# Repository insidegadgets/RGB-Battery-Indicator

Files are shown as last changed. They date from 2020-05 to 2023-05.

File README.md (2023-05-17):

# RGB-Battery-Indicator
Add an RGB battery indicator to any device you like to monitor the battery level.
Default firmware is for a LiPo.

License: CC-BY-NC

Order the board at 0.8mm thickness if installing in Gameboy. Likely some shell cutting will be required.
You'll need a programmer like a USBasp.
Check the picture for the parts placement.
Not recommended for beginners.

Order PCBs here or use the included gerbers:
https://oshpark.com/shared_projects/viN5ewHZ

ATTINY13A-MMFR

1M 0603

220K 0603

39K 0603

15K 0603

2x 5K 0603

2x 0.1uF 0603

1206 RGB LED - https://www.aliexpress.com/item/32382731373.html

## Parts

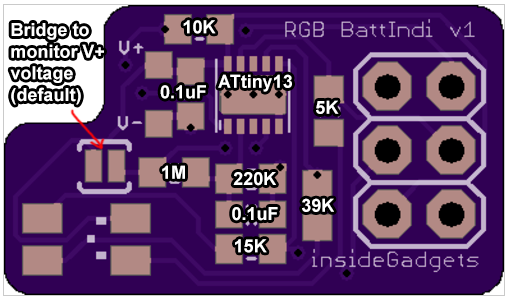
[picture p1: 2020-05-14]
Parts placement.png

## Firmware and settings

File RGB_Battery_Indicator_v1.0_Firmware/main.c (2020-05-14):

/*
 RGB Battery Indicator
 Version: 1.0
 Author: Alex from insideGadgets (www.insidegadgets.com)
 Created: 14/05/2020
 Last Modified: 14/05/2020
 
 Suitable for monitoring LiPo batteries
 
 */

#define F_CPU 1000000

#include <avr/io.h>
#include <avr/wdt.h>
#include <avr/interrupt.h>
#include <avr/sleep.h>
#include <util/delay.h>
#include "setup.c"

int main(void) {
	setup();
	
	uint8_t rgbColour = 0;
	
	while (1) {
		// 5 samples over 25ms
		uint16_t batteryVoltageLevel = 0;
		for (uint8_t x = 0; x < 5; x++) {
			batteryVoltageLevel += adc_read(batteryADCPin, ADC_REF_1_1V);
			_delay_ms(5);
		}
		batteryVoltageLevel = batteryVoltageLevel / 5;
		
		
		int greenHysterious = 0;
		int blueHysterious = 0;
		if (rgbColour == 2) { // Green
			greenHysterious = -10;
		}
		else if (rgbColour == 1) { // Blue
			greenHysterious = 10;
		}
		else { // Red
			blueHysterious = 10;
		}
		
		
		// Green
		if (batteryVoltageLevel >= (650 + greenHysterious)) { // 3.8v
			PORTB &= ~(1<<RGB_GREEN);
			PORTB |= (1<<RGB_RED);
			PORTB |= (1<<RGB_BLUE);
			rgbColour = 2;
		}
		
		// Blue
		else if (batteryVoltageLevel >= (580 + blueHysterious)) { // 3.3v
			PORTB &= ~(1<<RGB_BLUE);
			PORTB |= (1<<RGB_RED);
			PORTB |= (1<<RGB_GREEN);
			rgbColour = 1;
		}
		
		// Red
		else {
			PORTB &= ~(1<<RGB_RED);
			PORTB |= (1<<RGB_BLUE);
			PORTB |= (1<<RGB_GREEN);
			rgbColour = 0;
		}
		
		watchdog_sleep(T1S);
	}
	
	
	return 0;
}

EMPTY_INTERRUPT(ADC_vect);
EMPTY_INTERRUPT(WDT_vect);

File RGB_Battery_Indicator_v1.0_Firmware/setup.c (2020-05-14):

/*
 RGB Battery Indicator
 Version: 1.0
 Author: Alex from insideGadgets (www.insidegadgets.com)
 Created: 14/05/2020
 Last Modified: 14/05/2020

 */

#ifndef cbi
#define cbi(sfr, bit) (_SFR_BYTE(sfr) &= ~_BV(bit))
#endif
#ifndef sbi
#define sbi(sfr, bit) (_SFR_BYTE(sfr) |= _BV(bit))
#endif

#ifndef NULL
#define NULL ((void *)0)
#endif

#define LOW 0
#define HIGH 1
#define false 0
#define true 1

// Watchdog timeouts to values
#define T16MS 0
#define T32MS 1
#define T64MS 2
#define T128MS 3
#define T250MS 4
#define T500MS 5
#define T1S 6
#define T2S 7
#define T4S 8
#define T8S 9

#define ADC_REF_VCC 0
#define ADC_REF_1_1V 1

#define batteryADCPin 3

#define RGB_RED PB0
#define RGB_GREEN PB1
#define RGB_BLUE PB2

// Put the AVR in power down sleep mode
void system_sleep(void) {
	set_sleep_mode(SLEEP_MODE_PWR_DOWN); // Set sleep mode
	sleep_mode(); // System sleeps here
}

// Setup watchdog timed sequence
void setup_watchdog(uint8_t wdDelay) {
	if (wdDelay > 7) {
		wdDelay = wdDelay & 7;
		wdDelay |= (1<<5); // Set WDP3 bit
	}
	
	MCUSR &= ~(1<<WDRF); // Turn off flag
	WDTCR |= (1<<WDCE) | (1<<WDE); // Start timed sequence
	WDTCR = wdDelay | (1<<WDTIE); // Set new watchdog timeout value
}

// Turn off the Watchdog
void turn_off_watchdog(void) {
	cli(); // Turn interrupts off
	MCUSR &= ~(1<<WDRF);
	WDTCR |= (1<<WDCE) | (1<<WDE);
	WDTCR = 0;
	sei(); // Turn interrupts back on
}

// Watchdog sleep function - setup, sleep and turn off
void watchdog_sleep(uint8_t timeout) { 
	setup_watchdog(timeout);
	system_sleep();
	turn_off_watchdog();
}

// ADC Read
int adc_read(uint8_t pin, uint8_t reference) {
	uint8_t low, high;
	
	// Set the pin and ref
	if (reference == ADC_REF_1_1V) {
		ADMUX = (1<<REFS0) | (pin & 0x3F);
	}
	else {
		ADMUX = (pin & 0x3F);
	}
	
	set_sleep_mode(SLEEP_MODE_ADC); // Set sleep mode ADC
	sleep_mode(); // System sleeps here
	
	// we have to read ADCL first; doing so locks both ADCL
	// and ADCH until ADCH is read.  reading ADCL second would
	// cause the results of each conversion to be discarded,
	// as ADCL and ADCH would be locked when it completed.
	low = ADCL;
	high = ADCH;
	
	// combine the two bytes
	return (high << 8) | low;
}

// Setup the AVR
void setup(void) {
	// Set RGB outputs and all off
	DDRB |= (1<<PB2) | (1<<PB1) | (1<<PB0);
	PORTB |= (1<<PB2) | (1<<PB1) | (1<<PB0);
	
	// Wait a bit
	_delay_ms(250);
	
	// Set ADC prescale factor to 8
	// 1 MHz / 8 = 125 KHz, inside the desired 50-200 KHz range.
	sbi(ADCSRA, ADPS1);
	sbi(ADCSRA, ADPS0);
	
	// Enable ADC/interrupt
	sbi(ADCSRA, ADEN);
	sbi(ADCSRA, ADIE);
	
	sei(); // Turn on interrupts
}
